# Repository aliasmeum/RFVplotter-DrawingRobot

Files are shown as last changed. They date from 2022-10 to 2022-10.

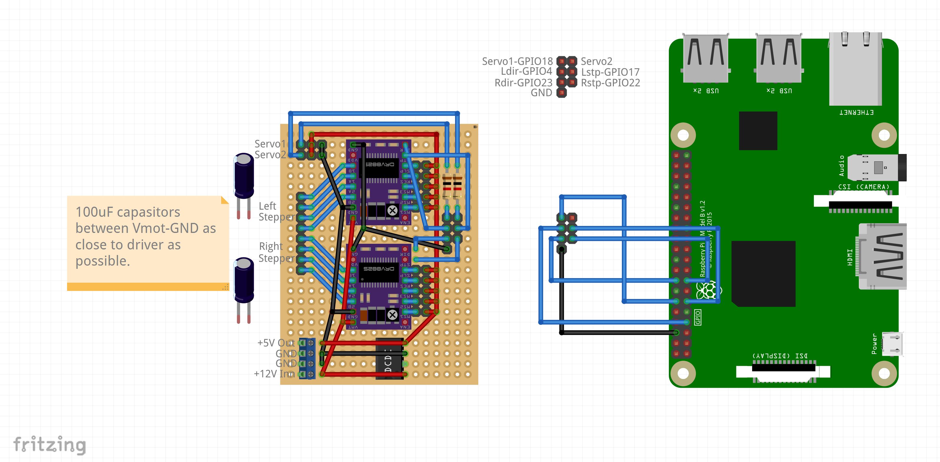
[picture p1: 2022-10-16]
RFVplotterWiring/RFVplotter-DRV8825-Perfboard-v1_0.JPG

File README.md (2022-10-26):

# RFVplotter-DrawingRobot
# 26.10.2022
# Warning! I have found some inconsistency between the code and the wiring-diagrams, something is not up to date and I am looking into it. I will update as soon as I have gone through all the files.

Design files are up to date 17.10.2022 and can be found here.
Build description will be made available on www.robertfriberg.no

# Credits #
-   Thanks to [Herbert Roider](https://github.com/bertlr) for the original vplotter program, and for the excellent instructions on installation and use.
    I have only modified the program to include a hardware PWM-control for a BLDC-motor. This drone-motor and propeller is used for pushing the plotter head against the paper.

-   Thanks to Niklas Johansson and Lars Aurtande for the inspiration to make my own vplotter.

# Installation of the vplotter program #

- Install Raspberry Pi OS: [www.raspberrypi.org/downloads/](https://www.raspberrypi.org/downloads/)

- Install necessary packages: git, cmake and flex

        sudo apt install git-core cmake flex

- Download and install WiringPi library

    I am no longer able to install the official wiringpi library from Gordon Henderson [wiringPi](http://wiringpi.com).
    I am now using an unofficial mirror from: [https://github.com/WiringPi/WiringPi](https://github.com/WiringPi/WiringPi)

        git clone https://github.com/WiringPi/WiringPi.git
        cd WiringPi
        sudo ./build
    
- For the BLDC-motor to work GPIO12 (wiringpi26) must be set to pwm-mode
        
        gpio mode 26 pwm

    Check that mode is set to ALT0 for wPi26
     
        gpio readall
   
    Warning! I am not able to set the gpio mode permanently to pwm, after reboot it has to be set again with: "gpio mode 26 pwm"
    I had no problem with this using the original wiringPi library, and I have currently no solution for this.

- Download and build vplotter

        git clone https://github.com/aliasmeum/RFVplotter-DrawingRobot.git
        cd RFVplotter-DrawingRobot-main\RFVplotterCode
        cmake .
        make
        sudo make install        

# Running the vplotter program #

The plotter needs some command line arguments:

- x0            :    Horizontal distance from center of the left stepper motor to the zero point on the canvas in mm.
- y0            :    Vertical distance from center of the left stepper motor to the zero point on the canvas in mm.
- baselength    :    The center distance between the stepper motors in mm.
- z_up          :    A value for the servo motor to lift the pen (1 - 100)
- z_down        :    A value for the servo motro to drop the pen (1 - 100)
- steps         :    Steps/mm for the plotter head. [Prusa calculator](https://blog.prusa3d.com/calculator_3416/)
- bldc_dutycycle: Dutycycle for the bldc motor (50-100). Set to 0 for running the plotter without the motor running.

Run the plotter as root:

    sudo vplotter --x0=557 --y0=660 --baselength=1114 --z_up=16 --z_down=20 --steps=80 --bldc_dutycycle=55

Run the plotter with a g-code file:

    sudo vplotter --x0=557 --y0=660 --baselength=1114 --z_up=16 --z_down=20 --steps=80 --bldc_dutycycle=55 < filename.ngc

Stop the plotter with <kbd>Ctrl</kbd>+<kbd>C</kbd>.

The Z-axis can lift or drop the pen. A value >0 lifts the pen and <=0 drops the pen.

    G0 Z0 (move the pen down)
    G0 Z1 (lift the pen up)

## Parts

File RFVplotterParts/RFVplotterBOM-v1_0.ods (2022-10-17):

RFVplotterBOM-v1_0
Category | Part number | Part name | Version number | Quantity | Description | Example links (Links are working 16.10.2022. Links will not be updated.)
Plotter head parts
Printed part | 1.1 | RFVplotter-FrontPlate | v1_0 | 1
Printed part | 1.2 | RFVplotter-BeltConnectorArm | v1_0 | 2
Printed part | 1.3 | RFVplotter-DistancePlate | v1_0 | 1
Printed part | 1.4 | RFVplotter-BackPlate | v1_0 | 1
Printed part | 1.5 | RFVplotter-PenLifterBody | v1_0 | 1
Printed part | 1.6 | RFVplotter-PenLifterServoPushBlock | v1_0 | 1
Printed part | 1.7 | RFVplotter-PenLifterPenHolder10p5mm | v1_0 | 1 | You can edit this file to fit a pen with smaller or bigger OD.
Printed part | 1.8 | RFVplotter-PenLifterLockWheel | v1_0 | 1
Printed part | 1.9 | RFVplotter-Riser10mm | v1_0 | 1 | Plotter can be used without the riser, but it angles the belts and gives a little more pressure on the pen and it is nice for cable management.
Printed part | 1.9-20 | RFVplotter-Riser20mm | v1_0 |  | When increasing the scale of the plotter you can increase the height of the riser. For more than 2m between the motors I use the 20mm riser.
Printed part | 1.10 | RFVplotter-WeightAdjustmentPlate | v1_0 | 1 | For balancing the plotter head.
Printed part | 1.11 | RFVplotter-WeightAdjustmentScrew | v1_0 | 2 | For balancing the plotter head.
Electro-mechanic part | 2.1 | ServoSG90 |  | 1 | Dimension: 22mm x 11.5mm x 22.5mm | https://www.aliexpress.com/item/32561052304.html?curPageLogUid=aEJHGl18hYbh
Electro-mechanic part | 2.2 | BLDC-Motor |  | 1 | 1806 2400KV, Stator diameter Ø18mm | https://www.aliexpress.com/item/32360078446.html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
Electro-mechanic part | 2.3 | BLDC-Propeller |  | 1 | DALPROP T3045BN | https://www.aliexpress.com/item/32791637052.html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
Electro-mechanic part | 2.4 | BLDC-PropellerSpinner |  | 1 | Included with BLDC motor.
Hardware | 3.1 | M3 Nylon insert locknut |  | 1
Hardware | 3.2 | M3 Nut |  | 7
Hardware | 3.3 | M3x30 Socket head screw |  | 1
Hardware | 3.4 | M3x25 Socket head screw |  | 3
Hardware | 3.5 | M3x33 Socket head screw |  | 1
Hardware | 3.6 | Ø3x16 Countersunk wood screw |  | 2
Hardware | 3.7 | Ø2x8 Servo screws |  | 2 | Included with servo motor.
Hardware | 3.8 | M2x4.5 BLDC screws |  | 4 | Included with BLDC motor.
Hardware | 3.9 | Ø3x42 Dowel pin |  | 1 | Aluminium knitting pin, cut to length. | https://www.aliexpress.com/item/4000270334571.html?curPageLogUid=ALd1h9LfMG6I
Fishing supplies | 4.1 | Weight 100g |  | 1 | Fishing sinker. Weight dependent of plotter size. | https://www.aliexpress.com/item/1005003163363896.html?curPageLogUid=He2kd8zySBwC
Drawing supplies | 5.1 | Drawing pen |  | 1 | Pilot drawing pen 0.5mm (OD=10.5mm) | https://www.pilotpen.eu/en/drawing-pen-05-fineliner-marker-pen-broad-tip.html
Peripheral parts
Printed part |  | RFVplotter-StepperMotorBracketLeft | v1_0 | 1
Printed part |  | RFVplotter-StepperMotorBracketRight | v1_0 | 1
Printed part |  | RFVplotter-BeltWeightIdlerHolder | v1_0 | 2 | Designed for use with 3mm threaded rod and coins with hole in.
Electro-mechanic part |  | Stepper motor NEMA17 |  | 2 |  | https://www.aliexpress.com/item/1005004586903773.html
Mechanical part |  | Stepper motor pulley |  | 2 | 2GT-6mm/20 teeth/5mm bore | https://www.aliexpress.com/item/32953778381.html?spm=a2g0o.order_list.0.0.608e1802ToJcnP
Mechanical part |  | Idler pulley for BeltWeights |  | 2 | 2GT-6mm/Ø10mm/3mm bore | https://www.aliexpress.com/item/32971394035.html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
Mechanical part |  | Timing belt 2GT-6mm |  | 2 | Length depending on plotter size. | https://www.aliexpress.com/item/32850595940.html
Electronic part |  | Raspberry Pi |  | 1 | Raspberry Pi 3 Model B+ or similar. | https://www.raspberrypi.com/products/
Electronic part |  | Power supply for Raspberry pi |  | 1 | 5.1V / 2.5A DC output. | https://www.raspberrypi.com/products/
Electronic part |  | BLDC-Electronic Speed Controller |  | 1 | SimonK 12A ESC | https://www.aliexpress.com/item/32850173168.html?spm=a2g0o.order_list.0.0.608e1802ToJcnP
Electronic part |  | Power plug for BLDC-ECS |  | 1 | Amass XT60H | https://www.aliexpress.com/item/32991415491.html?spm=a2g0o.order_list.0.0.608e1802ToJcnP
Electronic part |  | Bullet Banana Connector plug for ESC 2mm |  | 3 |  | https://www.aliexpress.com/item/1862028985.html?spm=a2g0o.order_list.0.0.608e1802ToJcnP
DRV8825 Version
Printed part |  | RFVplotter-PiAndMotorDriverMountingBracket | v1_0 | 1 | Designed for use with drivers mounted on perfboard.
Electronic part |  | Motor drivers-DRV8825 |  | 2 | DRV8825 or similar. | https://www.aliexpress.com/item/1005001636527600.html?curPageLogUid=B0Snu9AwA8eb
Electronic part |  | Power supply |  | 1 | 12V/3.33A power supply from an old laptop.
Electronic part |  | Perfboard 70mm x 50mm |  | 1 |  | https://www.ebay.co.uk/itm/223758179338
Electronic part |  | DC Buck Step down Adjustable Voltage Regulator |  | 1 | 12V to 5V supply for motor drivers and SG90-servo | https://www.ebay.co.uk/itm/254604769344
Electronic part |  | Electrolytic capasitor 100uF |  | 2 |  | https://www.aliexpress.com/item/32739085379.html?spm=a2g0o.order_list.0.0.48551802espbNp
Electronic part |  | Terminal block screw connector 2p |  | 2 |  | https://www.aliexpress.com/item/32694793102.html?scm_id=1007.13339.291025.0&scm-url=1007.13339.291025.0
Electronic part |  | Resistor 1kOhm |  | 2 |  | https://www.aliexpress.com/item/32847096736.html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
Electronic part |  | Female pin connector 8p |  | 4 |  | https://www.ebay.co.uk/itm/223478558792
Electronic part |  | Male pin connector 3p |  | 3 |  | https://www.ebay.co.uk/itm/203585637263
Electronic part |  | Male pin connector 4p |  | 3 |  | https://www.ebay.co.uk/itm/203585637263
Electronic part |  | Male pin connector 5p |  | 4 |  | https://www.ebay.co.uk/itm/203585637263
Electronic part |  | Pin Header Jumper block |  | 6 |  | https://www.aliexpress.com/item/4000540718136.html?spm=a2g0o.order_list.0.0.48551802espbNp
TB6600 Version
Printed part |  | RFVplotter-PSUMountingBracketLeft | v1_0 | 1
Printed part |  | RFVplotter-PSUMountingBracketRight | v1_0 | 1
Electronic part |  | Motor drivers-TB6600 |  | 2 | TB6600 or similar. | https://www.aliexpress.com/item/1005003984360265.html?curPageLogUid=4mndEW296J4V
Electronic part |  | Power supply |  | 1 | ATX power supply from an old computer.
Electronic part |  | Resistor 1kOhm |  | 1

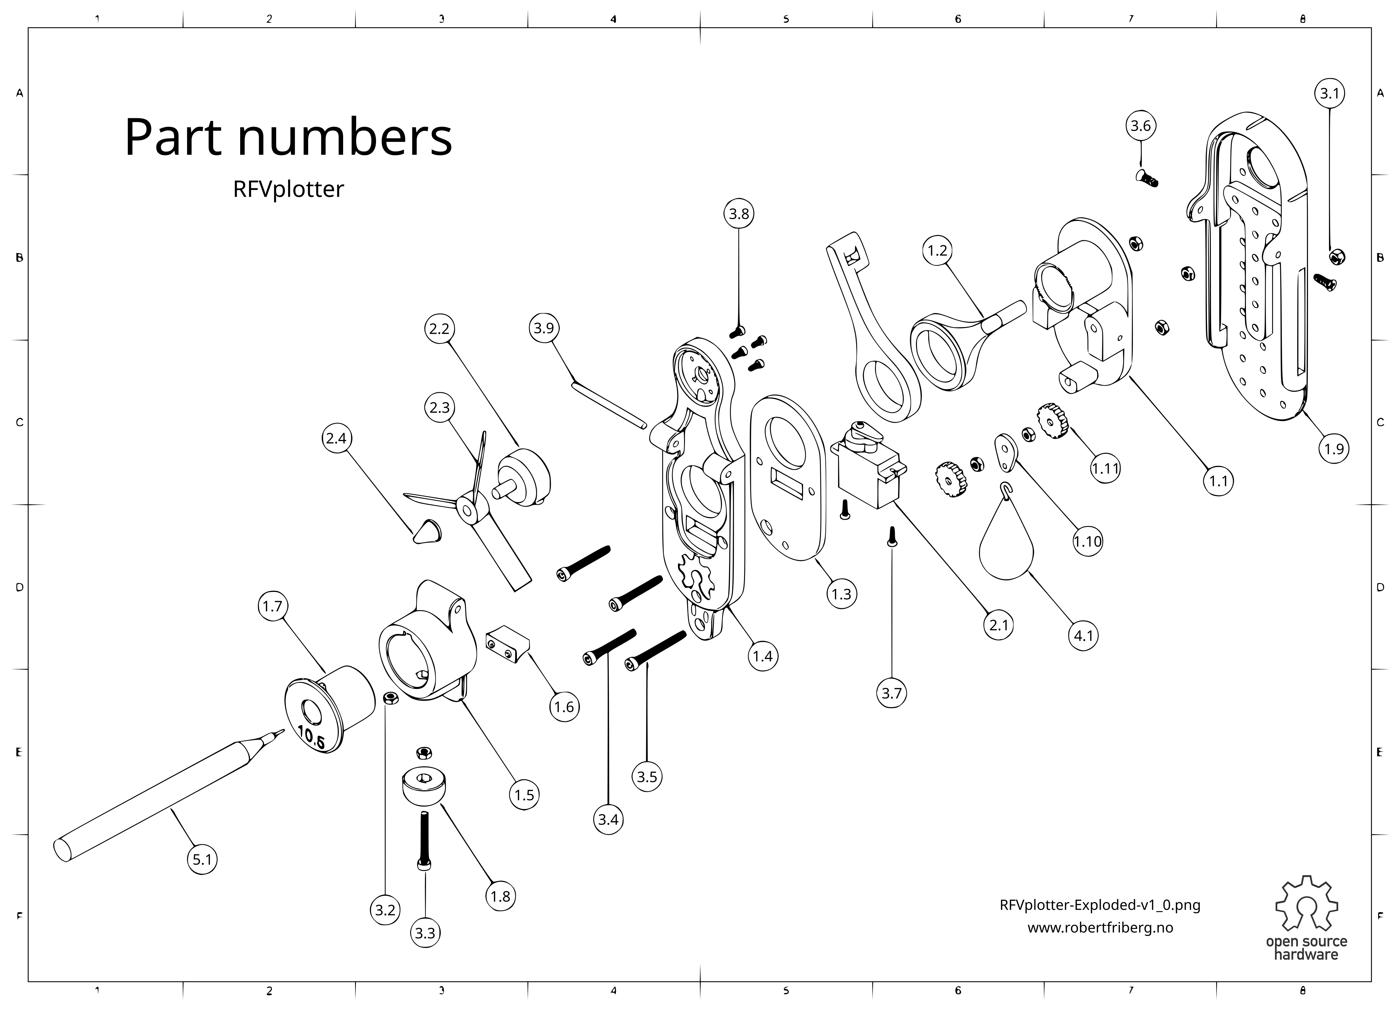
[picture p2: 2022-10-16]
RFVplotterParts/RFVplotterExploded-v1_0.png

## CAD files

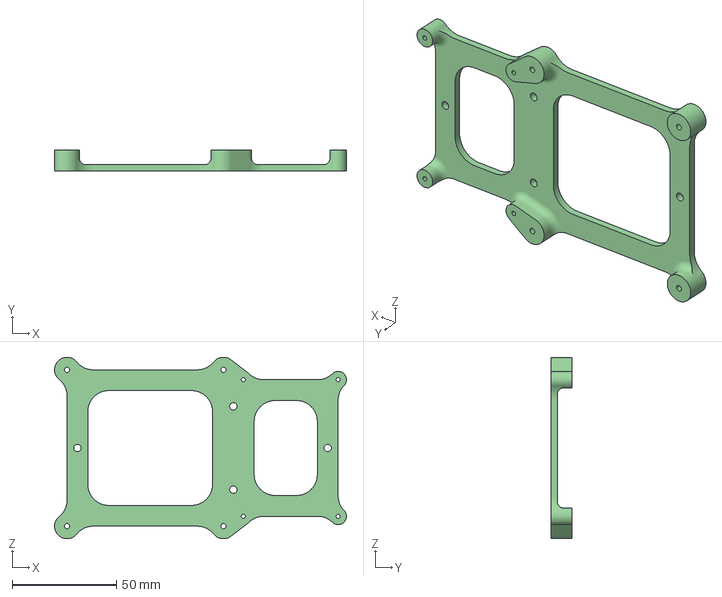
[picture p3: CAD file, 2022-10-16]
RFVplotterParts/DRV8825Parts/MeshFiles/RFVplotter-PiAndMotorDriverMountingBracket-v1_0.3mf
140.0 x 10.0 x 87.0 mm

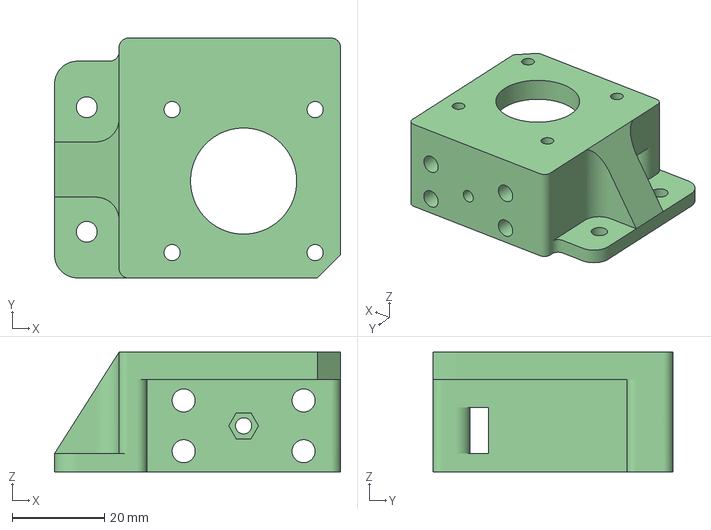
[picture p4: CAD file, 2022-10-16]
RFVplotterParts/PeripheralParts/MeshFiles/RFVplotter-StepperMotorBracketLeft-v1_0.3mf
62.0 x 52.0 x 26.0 mm

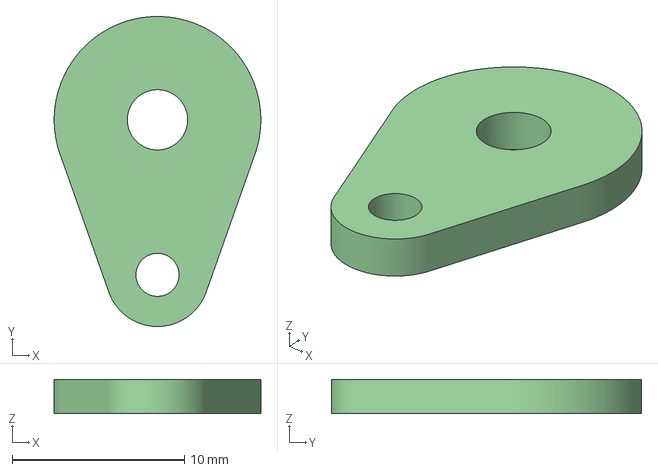
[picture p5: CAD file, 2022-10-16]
RFVplotterParts/PlotterHeadParts/MeshFiles/RFVplotter-WeightAdjustmentPlate-v1_0.3mf
12.0 x 18.0 x 2.00 mm

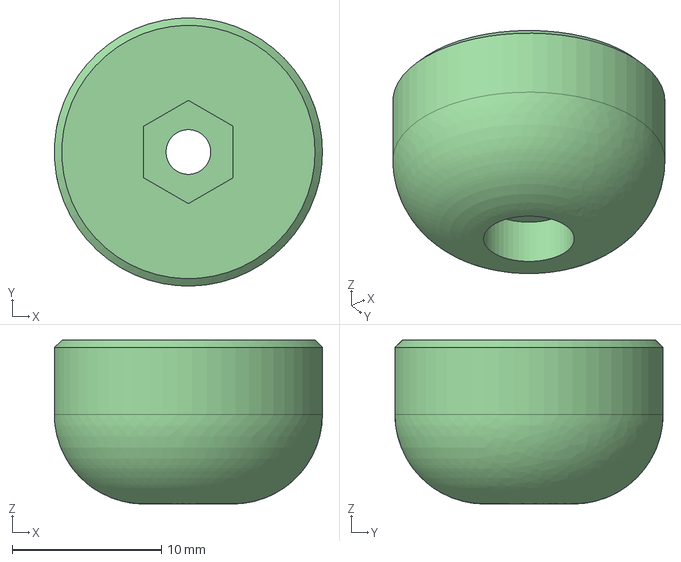
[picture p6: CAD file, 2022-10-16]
RFVplotterParts/PlotterHeadParts/StepFiles/RFVplotter-PenLifterLockWheel-v1_0.step
18.0 x 18.0 x 11.0 mm

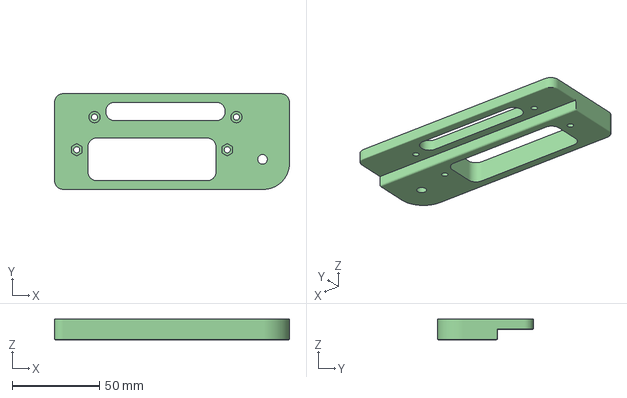
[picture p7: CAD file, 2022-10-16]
RFVplotterParts/TB6600Parts/MeshFiles/RFVplotter-PSUMountingBracketLeft-v1_0.3mf
135.0 x 55.0 x 12.0 mm

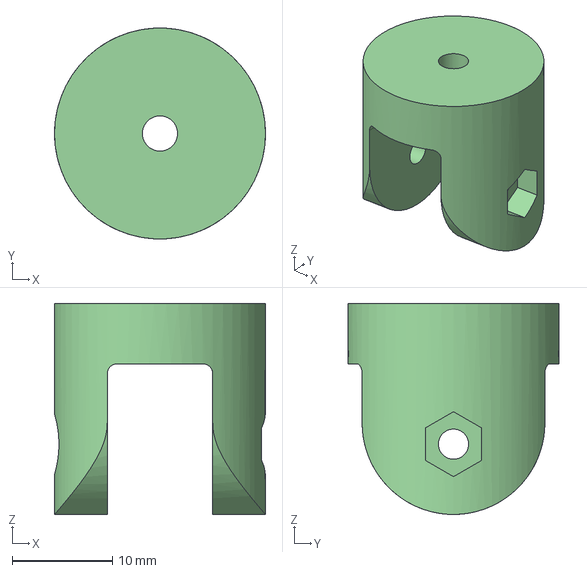
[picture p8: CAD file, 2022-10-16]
RFVplotterParts/PeripheralParts/StepFiles/RFVplotter-BeltWeightIdlerHolder-v1_0.step
21.0 x 21.0 x 21.0 mm

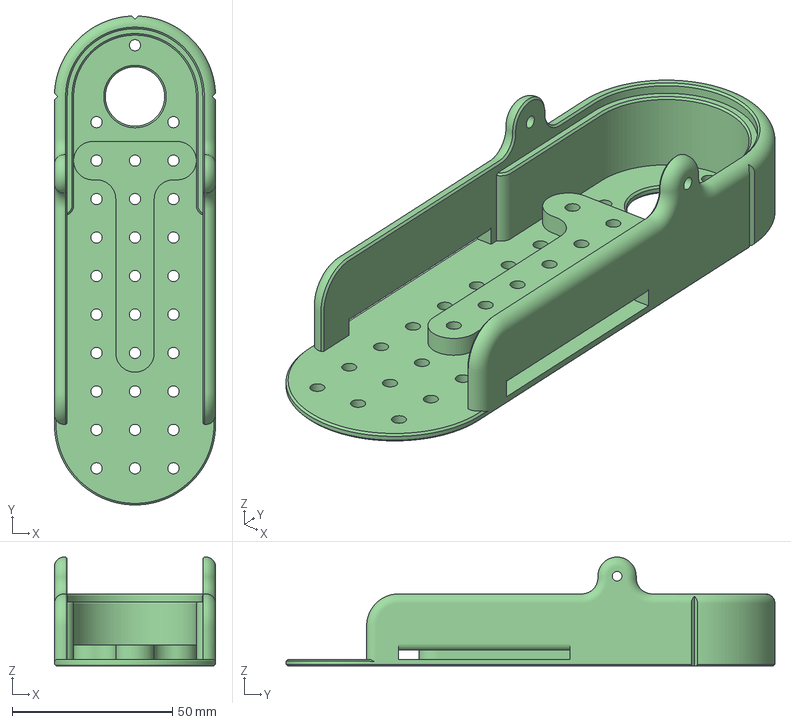
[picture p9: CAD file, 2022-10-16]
RFVplotterParts/PlotterHeadParts/MeshFiles/RFVPlotter-Riser20mm-v1_0.3mf
50.3 x 152.6 x 34.0 mm

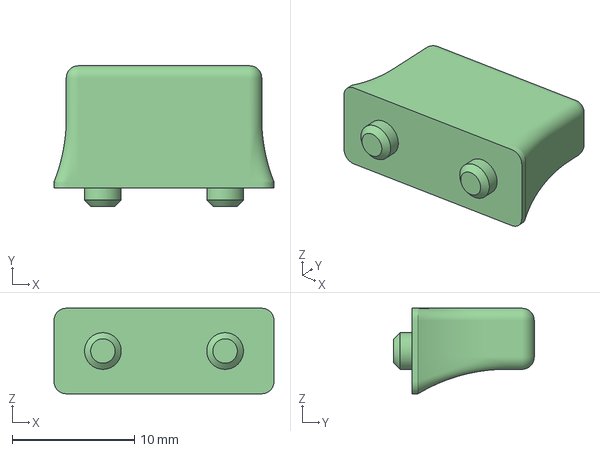
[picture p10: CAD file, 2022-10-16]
RFVplotterParts/PlotterHeadParts/MeshFiles/RFVplotter-PenLifterServoPushBlock-v1_0.3mf
18.0 x 11.5 x 7.00 mm

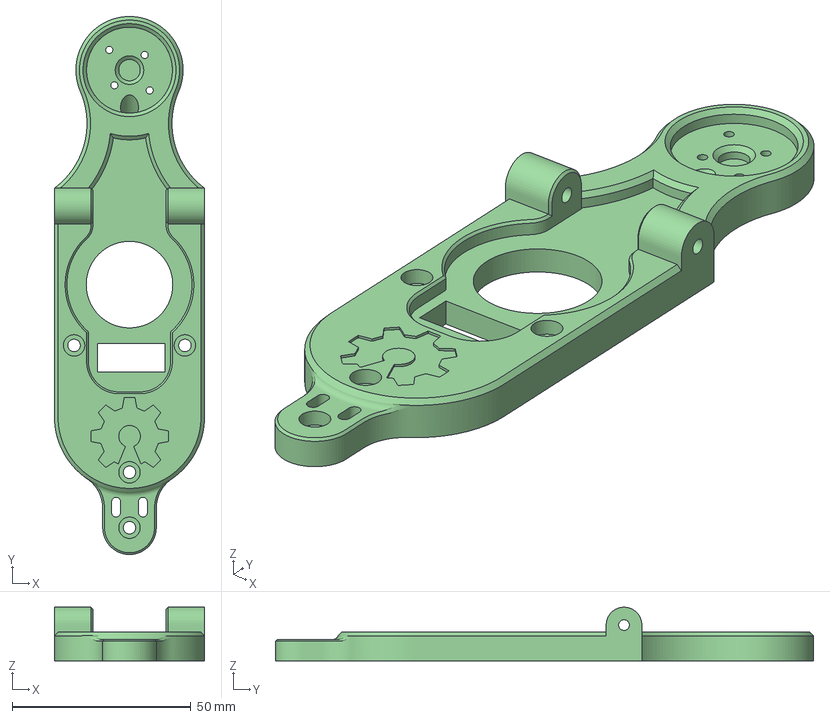
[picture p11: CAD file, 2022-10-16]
RFVplotterParts/PlotterHeadParts/MeshFiles/RFVplotter-BackPlate-v1_0.3mf
42.0 x 150.5 x 15.0 mm

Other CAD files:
RFVplotterParts/DRV8825Parts/StepFiles/RFVplotter-PiAndMotorDriverMountingBracket-v1_0.step
RFVplotterParts/PeripheralParts/StepFiles/RFVplotter-StepperMotorBracketRight-v1_0.step
RFVplotterParts/TB6600Parts/StepFiles/RFVplotter-PSUMountingBracketRight-v1_0.step
RFVplotterParts/PeripheralParts/MeshFiles/RFVplotter-StepperMotorBracketRight-v1_0.3mf
RFVplotterParts/TB6600Parts/MeshFiles/RFVplotter-PSUMountingBracketRight-v1_0.3mf
RFVplotterParts/TB6600Parts/StepFiles/RFVplotter-PSUMountingBracketLeft-v1_0.step
RFVplotterParts/PeripheralParts/MeshFiles/RFVplotter-BeltWeightIdlerHolder-v1_0.3mf
RFVplotterParts/PeripheralParts/StepFiles/RFVplotter-StepperMotorBracketLeft-v1_0.step
RFVplotterParts/PlotterHeadParts/StepFiles/RFVplotter-WeightAdjustmentPlate-v1_0.step
RFVplotterParts/DRV8825Parts/RFVplotter-PiAndMotorDriverMountingBracket-v1_0.f3d
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

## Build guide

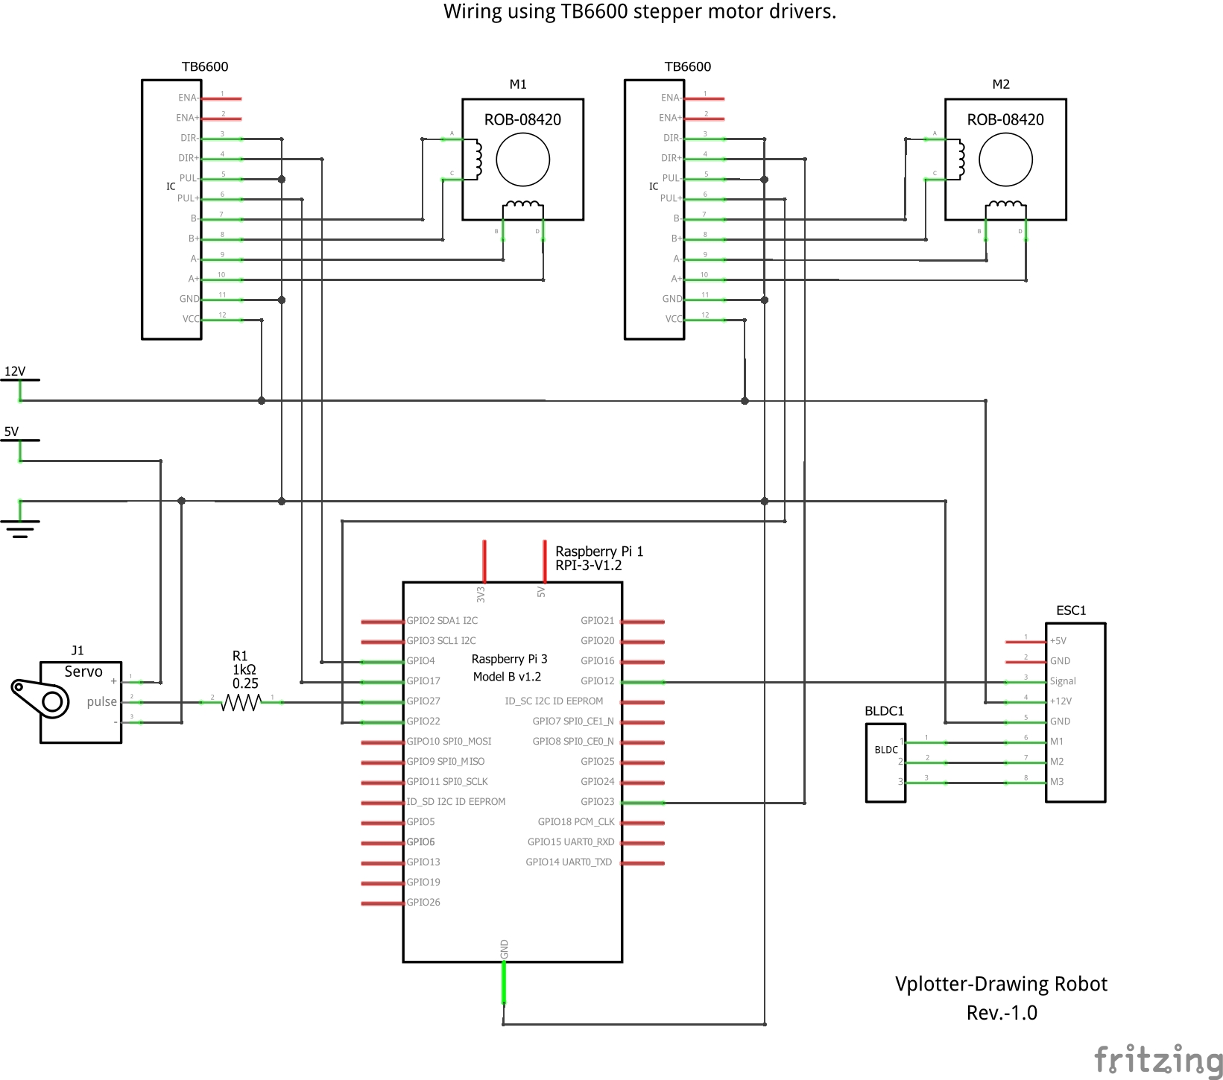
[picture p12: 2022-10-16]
RFVplotterWiring/RFVplotter-TB6600-v1_0.jpg

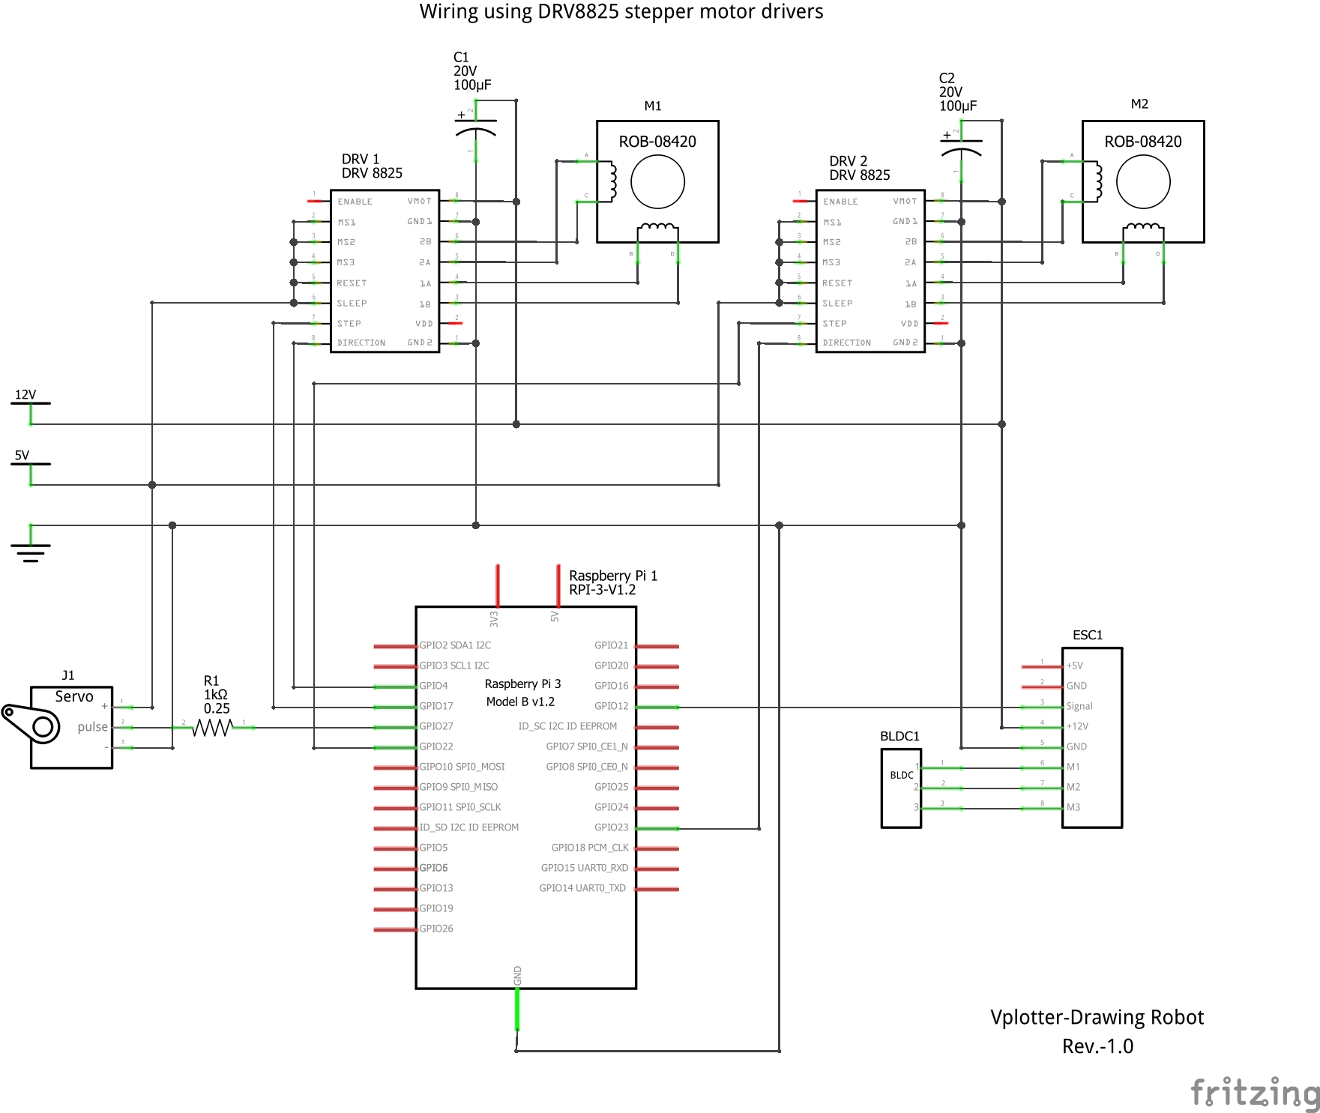
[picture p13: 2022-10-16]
RFVplotterWiring/RFVplotter-DRV8825-v1_0.jpg

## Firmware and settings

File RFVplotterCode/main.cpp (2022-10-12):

/*
Added PWM-control for a BLDC-motor.
By Robert Friberg

This version:
Stopping bldc after M30

Previous version:
Sanity check for bldc_dc values is working.

Previous version:
Experimenting with sanity check for bldc_dutycycle.

Previous version:
Experimenting with stopping the bldc motor on ctrl+c
Program catches ctrl+c and stops bldc motor before exit.

Previous version:
Experimenting with generating pwm output for bldc.
Catching command line argument for bldc_dutycycle. Calling function for starting and stopping the bldc motor.

Previous version:
Experimenting with bldc-ds argument at startup.
Argument for bldc_dutycycle working. Not doing anything with it yet.

Previous version:
In Machine.cpp - Moving Z_SERVO from wiringPi pin 1 to pin 2, freeing pin 1 for the bldc motor.
wiringPi only supports hardware pwm on pin 1.
No other changes in original code.
*∕

/*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
 *   (at your option) any later version.                                   *
 *                                                                         *
 *   This program is distributed in the hope that it will be useful,       *
 *   but WITHOUT ANY WARRANTY; without even the implied warranty of        *
 *   MERCHANTABILITY or FITNESS FOR A PARTICULAR PURPOSE.  See the         *
 *   GNU General Public License for more details.                          *
 *                                                                         *
 *   You should have received a copy of the GNU General Public License     *
 *   along with this program; if not, write to the                         *
 *   Free Software Foundation, Inc.,                                       *
 *   59 Temple Place - Suite 330, Boston, MA  02111-1307, USA.             *
 ***************************************************************************/

/* 
 * File:   main.cpp
 * Author: Herbert Roider <herbert@roider.at>
 *
 * Created on 12. Februar 2016, 22:15
 */

#include <iostream>
#include <sstream>
#include <fstream>
#include <math.h>
#include <stdlib.h>
#include <unistd.h>
#include <string>
#include <limits>
#include <cfloat>
#include "Machine.h"
#include "Geometry.h"
#include <getopt.h>
#include <signal.h>

// siehe manpages flex :
#undef yyFlexLexer
#define yyFlexLexer xxFlexLexer
#include <FlexLexer.h>

//RF: Function declaration for bldc motor
void startstopBLDC(int);
//RF: Function declaration for SIGINT signal handling (Catching ctrl+c)
void sigintHandler(int signum);

/*
 * 
 */
int main(int argc, char** argv) {

//RF: SIGINT handling catching ctrl+c
signal(SIGINT, sigintHandler);

    double x = 0.0;
    double y = 0.0;
    double z = 1.0;
    double r = DBL_MAX; // radius
    double i = DBL_MAX;
    double j = DBL_MAX;
    double f = 0.0; // feed in mm/min, 0 is rapid speed

    int M_command = -1;
    int G_command = -1;
    // Fact to convert the values, used when inches:
    double to_metric = 1.0;

    double base_length = 650.0;
    double x0 = 100.0;
    double y0 = -700.0;
    double stepsPermm = 40.0;
    int servo_up = 13;
    int servo_down = 8;
    int bldc_dc = 0; //RF: Dutycycle for the bldc motor.

    int c;
    int count_options = 0;
    // Read the options
    while (1) {
        static struct option long_options[] = {

            /* These options don’t set a flag.
               We distinguish them by their indices. */
            {"baselength", required_argument, 0, 'b'},
            {"y0", required_argument, 0, 'y'},
            {"x0", required_argument, 0, 'x'},
            {"steps", required_argument, 0, 's'},
            {"z_up", required_argument, 0, 'u'},
            {"z_down", required_argument, 0, 'd'},
            {"bldc_dutycycle", required_argument, 0, 'm'}, //RF: bldc motor.

            {0, 0, 0, 0}
        };
        /* getopt_long stores the option index here. */
        int option_index = 0;

        c = getopt_long(argc, argv, "b:y:x:s:u:d:m:",           //RF: bldc motor. Added m: Changed p to d.
                long_options, &option_index);

        /* Detect the end of the options. */
        if (c == -1)
            break;

        switch (c) {


            case 'b':
                base_length = atof(optarg);
                std::cout << "baselength = " << base_length << std::endl;
                count_options++;
                break;

            case 'y':
                y0 = atof(optarg);
                std::cout << "y0 = " << y0 << std::endl;
                count_options++;
                break;

            case 'x':
                x0 = atof(optarg);
                std::cout << "x0 = " << x0 << std::endl;
                count_options++;
                break;

            case 's':
                stepsPermm = atof(optarg);
                std::cout << "steps = " << stepsPermm << std::endl;
                count_options++;
                break;

            case 'u':
                servo_up = atoi(optarg);
                std::cout << "z_up = " << servo_up << std::endl;
                count_options++;
                break;

            case 'd':
                servo_down = atof(optarg);
                std::cout << "z_down = " << servo_down << std::endl;
                count_options++;
                break;

            case 'm':                                                    //RF: bldc motor. Added case m. Changet atof to atoi.
                bldc_dc = atoi(optarg);
                std::cout << "bldc_dutycycle = " << bldc_dc << std::endl;
                count_options++;
                break;

            default:
                abort();
        }
    }
    if (count_options < 7) {                                            //RF: bldc motor. Changed from 6 to 7
        std::cout << "Not all options are set" << std::endl;
        exit(1);
    }

    //RF: Sanity check for bldc_dc values
    if (bldc_dc != 0 && bldc_dc < 50 || bldc_dc > 100)
    {
        std::cout << "The value for bldc_dutycycle must be between 50 and 100" << std::endl;
        std::cout << "For running the plotter without the bldc running, set bldc_dutycycle to 0" << std::endl;
        exit(1);
    }


    // end read options

    std::cout << "--------------------------------------------------------------" << std::endl
            << "                  VPLOTTER                                    " << std::endl
            << "--------------------------------------------------------------" << std::endl;


   
    //RF: Calling function to start bldc motor
    if (bldc_dc != 0)
    {
        std::cout << "Starting BLDC-Motor" << std::endl;
        startstopBLDC(bldc_dc);
    }
    
    Machine m(base_length, x0, y0, stepsPermm, servo_down, servo_up);
    std::cout << "Vplotter started" << std::endl;                      //RF: Changed from "started" to "Vplotter started"

    std::string line;
    int linenumber = 0;
    while (std::getline(std::cin, line)) {
        std::stringstream is;
        std::stringstream os;
        linenumber++;

        is << line;

        std::cout << line;
        // parse one line:
        xxFlexLexer lexer(&is, &os); // das prefix "xx" siehe flexerfile
        int ret = 0;
        do {
            int G;
            ret = lexer.yylex();
            std::string s = lexer.YYText();
            s.erase(0, 1);
            if (ret == 1) {
                G = ::atoi(s.c_str());
                switch (G) {
                    case 0:
                    case 1:
                    case 2:
                    case 3:
                        G_command = G;
                        break;
                    case 20:
                        to_metric = 25.4;
                        break;
                    case 21:
                        to_metric = 1.0;
                        break;
                }

            } else if (ret == 2) {
                x = ::atof(s.c_str()) * to_metric;
            } else if (ret == 3) {
                y = ::atof(s.c_str()) * to_metric;
            } else if (ret == 4) {
                z = ::atof(s.c_str()) * to_metric;
            } else if (ret == 5) {
                M_command = ::atoi(s.c_str());
            } else if (ret == 6) {
                r = ::atof(s.c_str()) * to_metric;
            } else if (ret == 7) {
                i = ::atof(s.c_str()) * to_metric;
            } else if (ret == 8) {
                j = ::atof(s.c_str()) * to_metric;
            } else if (ret == 9) {
                f = ::atof(s.c_str()) * to_metric;
            }
        } while (ret != 0);

        // Execute on line:

        if (M_command == 30) {
            m.penDown(false);
            m.MoveToPoint(0.0, 0.0, 0.0);
            if (bldc_dc != 0)              // RF
            {
                startstopBLDC(0);
            }
            return 0;

        }

        // movement
        if (G_command == 0 || G_command == 1 || G_command == 2 || G_command == 3) {
            if (z > 0) {
                m.penDown(false);
            } else {
                m.penDown(true);
            }
            if (G_command == 1 || G_command == 2 || G_command == 3) {
                if (f <= 0.0) {
                    std::cout << "Error: no feed rate (f.e.: F400)" << std::endl;
                    exit(1);
                }
            }

            std::cout << " --> " << linenumber << ": ";
            if (G_command == 0) {
                std::cout << "   -> rapid  to: " << x << ", " << y << std::endl;
                m.MoveToPoint(x, y, 0.0);
            } else if (G_command == 1) {
                std::cout << "   -> line  to: " << x << ", " << y << ", f=" << f << std::endl;
                m.MoveToPoint(x, y, f);
            } else if (G_command == 2 || G_command == 3) {

                bool ccw;
                // G2 clockwise, G3 counter clockwise
                if (G_command == 2) {
                    ccw = false;
                } else {
                    ccw = true;
                }
                // either r (radius) or i and k (relative center point coordinates)
                if (r == DBL_MAX & i < DBL_MAX && j < DBL_MAX) {
                    r = sqrt(i * i + j * j);
                }
                if (r == DBL_MAX) {
                    std::cout << "Error: either R or I and J" << std::endl;
                    exit(1);
                } 
                std::cout << "   -> arc to: " << x << ", " << y << " r=" << r << std::endl;
                Geometry g;
                std::vector<Point> points = g.getArcPolygon(Point(m.getX(), m.getY()), Point(x, y), r, ccw);
                for (int i = 0; i < points.size(); i++) {
                    //std::cout << points[i].x << ", " << points[i].y << std::endl;
                    m.MoveToPoint(points[i].x, points[i].y, f);
                }
            }

        }

        //std::cout << "x =" << x << " y=" << y << std::endl;

        M_command = -1;

        r = DBL_MAX; // radius
        i = DBL_MAX;
        j = DBL_MAX;



    }
    //RF: Calling function to stop bldc motor
    if (bldc_dc != 0)              // RF
        {
            startstopBLDC(0);
        }

    std::cout << "Finish" << std::endl;
    return 0;
}

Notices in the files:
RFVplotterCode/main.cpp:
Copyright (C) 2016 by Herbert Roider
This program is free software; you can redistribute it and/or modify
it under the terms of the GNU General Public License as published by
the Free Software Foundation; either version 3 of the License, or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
